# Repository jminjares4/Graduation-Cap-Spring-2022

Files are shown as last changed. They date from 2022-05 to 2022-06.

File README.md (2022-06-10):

# Graduation Cap Spring 2022 :zap:

## **Description**
This upcoming May, I will be graduating with my **Master of Science in Computer Engineering** from [The University of Texas at El Paso](https://www.utep.edu/engineering/ece/index.html)! Therefore, I decided to create a custom graduation cap to decorate as a true *engineer*. The graduation cap will utlize ARM Cortex M0 microcontroller with addtional sensors, LEDs, and NFC to store data.

## **Firmware**
- [x] Utlize open source Real-Time Operating System: [FreeRTOS]()
- [x] ARM Cortex M0+ micocontroller
- [x] Low power mode
- [x] custom drivers
## **Hardware**
- [x] Fixed USB data lines
  - [x] Update USB &pm; datalines with 90 ohms impedance
- [x] Open source development Electronic Design Automation (EDA): [KiCad]()
- [x] Two layer Printed Circuit Board (PCB)
- [x] Source Components
  - [x] LEDs
  - [x] ADLX335
  - [x] Lithium battery
  - [x] RP2040 custom board
- [x] Developed schematic
- [x] Developed printed circuit board
- [x] Board layout 4.74" * 4.74" with 45 degree rotation

## **Graduation Cap**
 

## **Development**
|**Software** | **Microcontroller** | **Hardware Design** |
| :---: | :---: | :---: |
| |  |  |

## **Author:**
* [**Jesus Minjares**](https://github.com/jminjares4)<br>
  * Master of Science in Computer Engineering<br>
 


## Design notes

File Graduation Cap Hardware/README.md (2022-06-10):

# Graduation Cap Spring 2022 :zap:
## **Description**

The graduation cap was developed KiCad.



## **Hardware**
- [x] Open source development Electronic Design Automation (EDA): [KiCad]()
- [x] Two layer Printed Circuit Board (PCB)
- [x] Source Components
  - [x] LEDs
  - [x] ADLX335
  - [x] Lithium battery
  - [x] RP2040 custom board
- [x] Developed schematic
- [x] Developed printed circuit board
- [x] Board layout 4.74" * 4.7" with 45 degree rotation

## **Graduation Schematic**
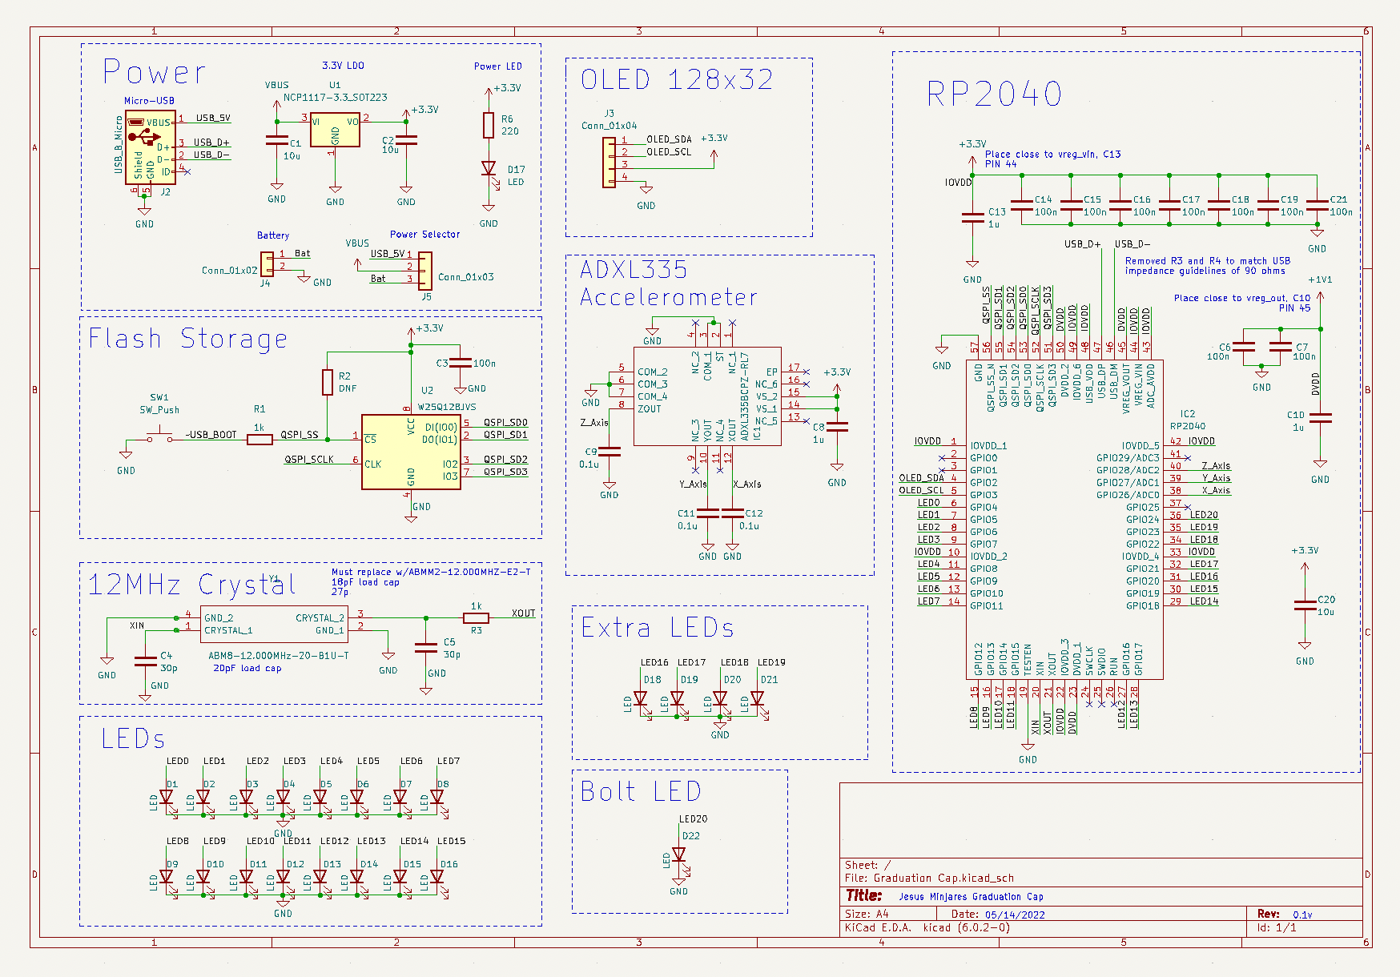
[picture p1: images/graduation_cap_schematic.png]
Schematic


## **Graduation Cap PCB**
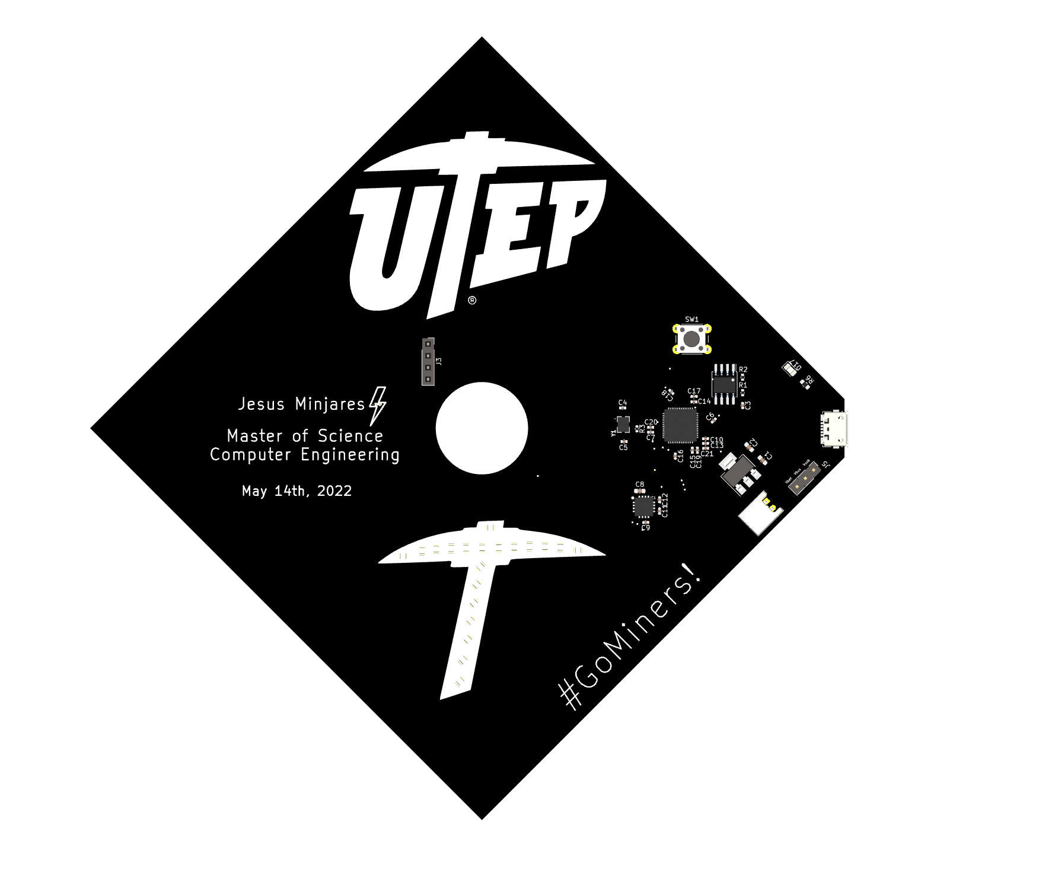
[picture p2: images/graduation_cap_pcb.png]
PCB

## **Author:**
* [**Jesus Minjares**](https://github.com/jminjares4)<br>
  * Master of Science in Computer Engineering<br>
 


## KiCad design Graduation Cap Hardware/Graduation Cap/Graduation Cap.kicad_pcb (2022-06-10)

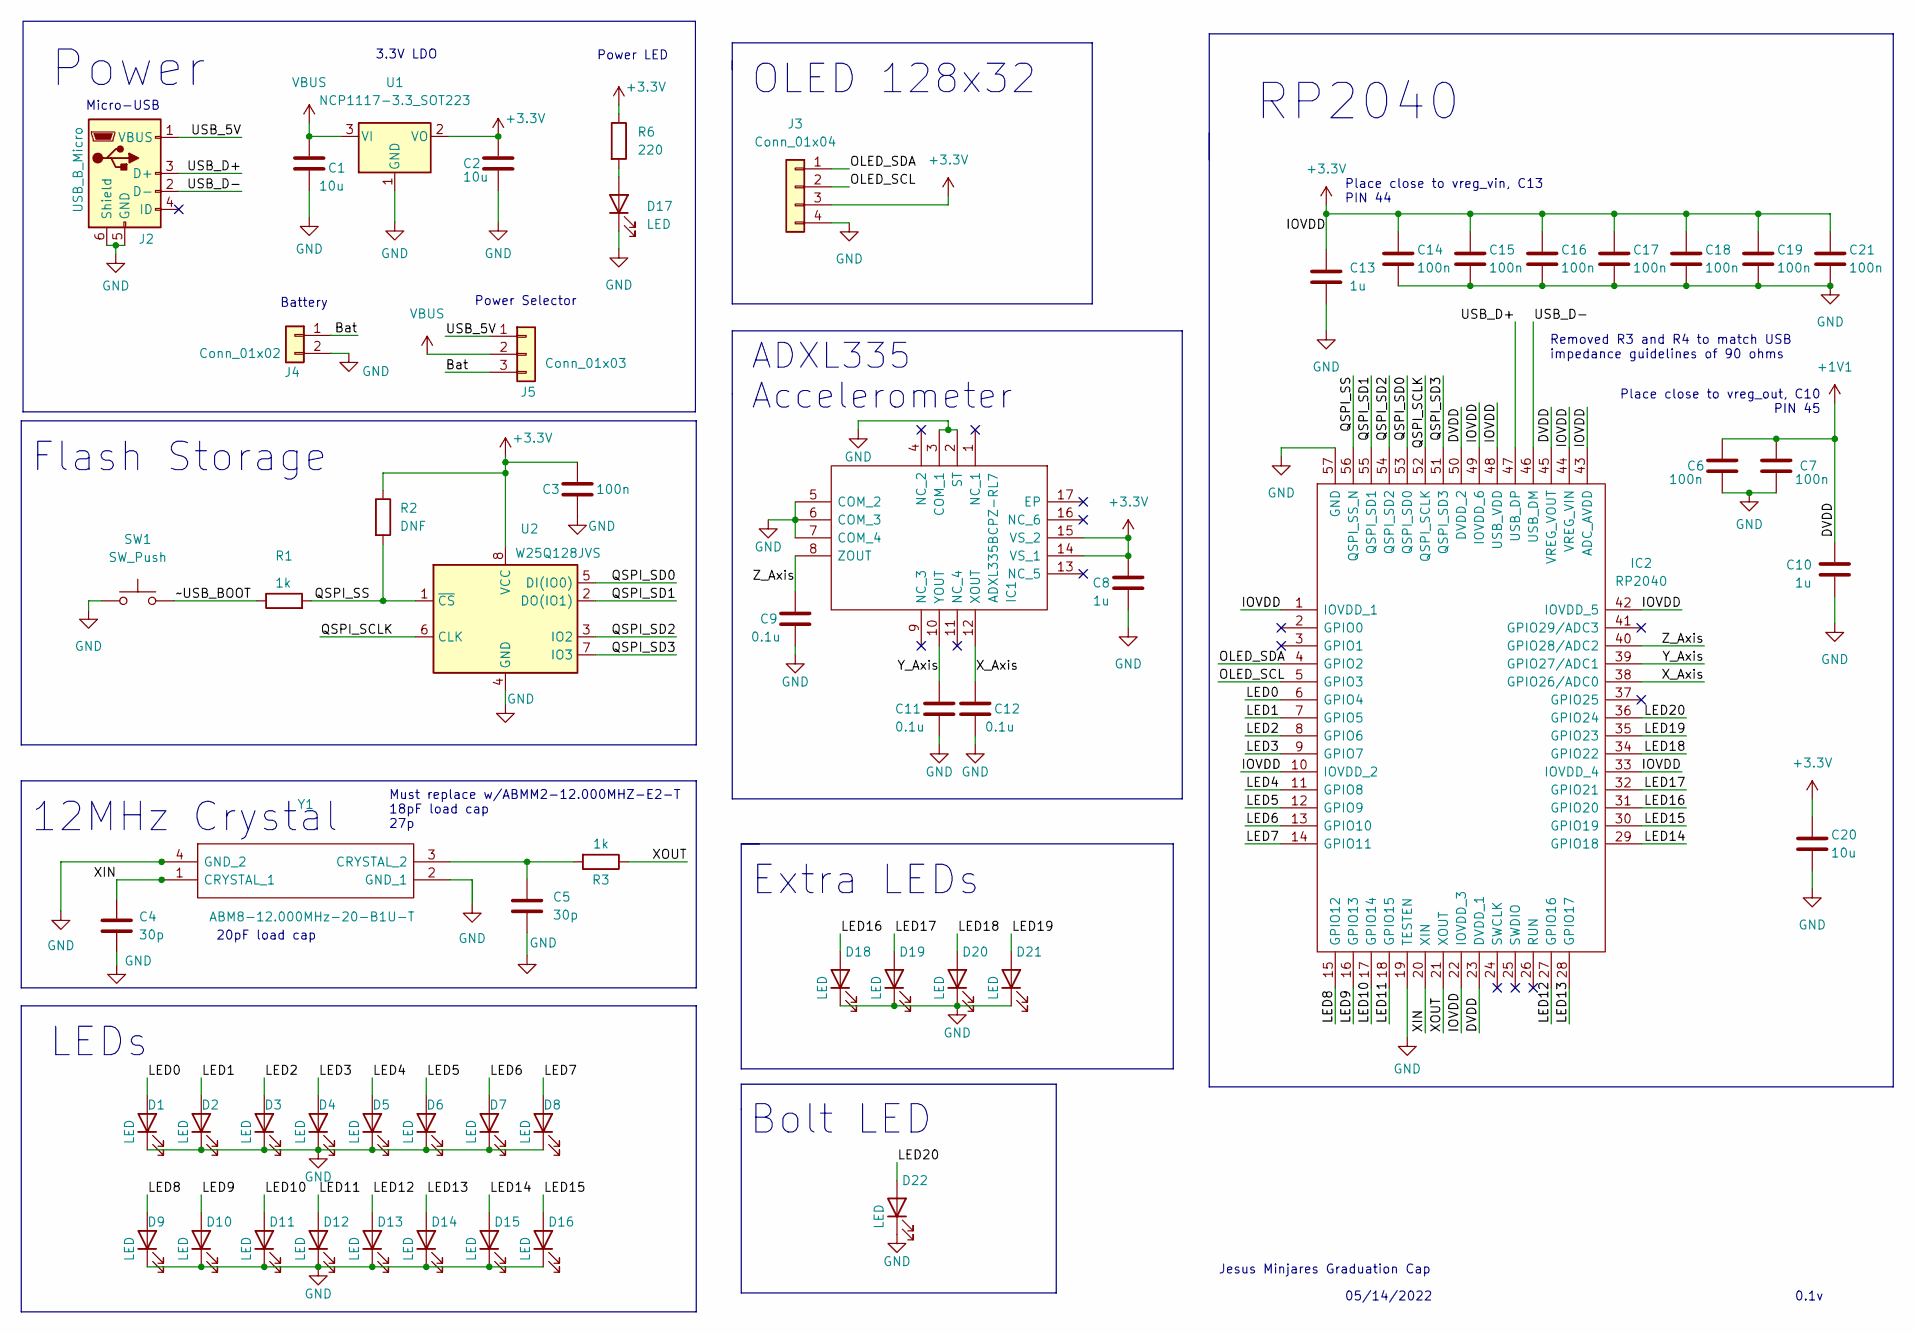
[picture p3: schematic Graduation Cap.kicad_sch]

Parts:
C1, C2: 10u; C_0603_1608Metric
C3, C6, C7, C14, C15, C16, C17, C18, C19, C21: 100n; C_0402_1005Metric
C4, C5: 30p; C_0402_1005Metric
C8: 1u; C_0603_1608Metric
C9, C11, C12: 0.1u; C_0402_1005Metric
C10, C13: 1u; C_0402_1005Metric
C20: 10u; C_0402_1005Metric
D1, D2, D3, D4, D5, D6, D7, D8, D9, D10, D11, D12, D13, D14, D15, D16, D17, D18, D19, D20, D21: LED; LED_0805_2012Metric
D22: LED; LED_0402_1005Metric
IC1: ADXL335BCPZ-RL7; QFN65P400X400X150-17N-D; Manufacturer_Part_Number ADXL335BCPZ-RL7; Mouser Part Number 584-ADXL335BCPZ-R7
IC2: RP2040; QFN40P700X700X90-57N-D; Manufacturer_Part_Number RP2040
J2: USB_B_Micro; USB_Micro-B_Molex_47346-0001
J3: Conn_01x04; PinSocket_1x04_P2.54mm_Vertical
J4: Conn_01x02; JST_PH_S2B-PH-K_1x02_P2.00mm_Horizontal
J5: Conn_01x03; PinHeader_1x03_P2.54mm_Vertical
R1, R3: 1k; R_0402_1005Metric
R2: DNF; R_0402_1005Metric
R6: 220; R_0603_1608Metric
SW1: SW_Push; SW_PUSH_6mm
U1: NCP1117-3.3_SOT223; SOT-223-3_TabPin2
U2: W25Q128JVS; SOIC-8_5.23x5.23mm_P1.27mm
Y1: ABM8-12.000MHz-20-B1U-T; ABM812000MHz20B1UT; Manufacturer_Part_Number ABM8-12.000MHz-20-B1U-T; Mouser Part Number 815-M812000MHZ20B1UT

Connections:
+1V1: C6.1, C7.1, C10.1, IC2.23 (DVDD_1), IC2.45 (VREG_VOUT), IC2.50 (DVDD_2)
+3V3: C2.1, C3.1, C8.2, C13.1, C14.1, C15.1, C16.1, C17.1, C18.1, C19.1, C20.1, C21.1, IC1.14 (VS_1), IC1.15 (VS_2), IC2.1 (IOVDD_1), IC2.10 (IOVDD_2), IC2.22 (IOVDD_3), IC2.33 (IOVDD_4), IC2.42 (IOVDD_5), IC2.43 (ADC_AVDD), IC2.44 (VREG_VIN), IC2.48 (USB_VDD), IC2.49 (IOVDD_6), J3.3, R2.1, R6.1, U1.2 (VO), U2.8 (VCC)
/Bat: J4.1, J5.3
/LED0: D1.2 (A), IC2.6 (GPIO4)
/LED1: D2.2 (A), IC2.7 (GPIO5)
/LED2: D3.2 (A), IC2.8 (GPIO6)
/LED3: D4.2 (A), IC2.9 (GPIO7)
/LED4: D5.2 (A), IC2.11 (GPIO8)
/LED5: D6.2 (A), IC2.12 (GPIO9)
/LED6: D7.2 (A), IC2.13 (GPIO10)
/LED7: D8.2 (A), IC2.14 (GPIO11)
/LED8: D9.2 (A), IC2.15 (GPIO12)
/LED9: D10.2 (A), IC2.16 (GPIO13)
/LED10: D11.2 (A), IC2.17 (GPIO14)
/LED11: D12.2 (A), IC2.18 (GPIO15)
/LED12: D13.2 (A), IC2.27 (GPIO16)
/LED13: D14.2 (A), IC2.28 (GPIO17)
/LED14: D15.2 (A), IC2.29 (GPIO18)
/LED15: D16.2 (A), IC2.30 (GPIO19)
/LED16: D18.2 (A), IC2.31 (GPIO20)
/LED17: D19.2 (A), IC2.32 (GPIO21)
/LED18: D20.2 (A), IC2.34 (GPIO22)
/LED19: D21.2 (A), IC2.35 (GPIO23)
/LED20: D22.2 (A), IC2.36 (GPIO24)
/OLED_SCL: IC2.5 (GPIO3), J3.2
/OLED_SDA: IC2.4 (GPIO2), J3.1
/QSPI_SCLK: IC2.52 (QSPI_SCLK), U2.6 (CLK)
/QSPI_SD0: IC2.53 (QSPI_SD0), U2.5 (DI(IO0))
/QSPI_SD1: IC2.55 (QSPI_SD1), U2.2 (DO(IO1))
/QSPI_SD2: IC2.54 (QSPI_SD2), U2.3 (IO2)
/QSPI_SD3: IC2.51 (QSPI_SD3), U2.7 (IO3)
/QSPI_SS: IC2.56 (QSPI_SS_N), R1.2, R2.2, U2.1 (~CS)
/USB_5V: J2.1 (VBUS), J5.1
/USB_D+: IC2.47 (USB_DP), J2.3 (D+)
/USB_D-: IC2.46 (USB_DM), J2.2 (D-)
/XIN: C4.1, IC2.20 (XIN), Y1.1 (CRYSTAL_1)
/XOUT: IC2.21 (XOUT), R3.1
/X_Axis: C12.2, IC1.12 (XOUT), IC2.38 (GPIO26/ADC0)
/Y_Axis: C11.1, IC1.10 (YOUT), IC2.39 (GPIO27/ADC1)
/Z_Axis: C9.1, IC1.8 (ZOUT), IC2.40 (GPIO28/ADC2)
/~USB_BOOT: R1.1, SW1.2
GND: C1.2, C2.2, C3.2, C4.2, C5.2, C6.2, C7.2, C8.1, C9.2, C10.2, C11.2, C12.1, C13.2, C14.2, C15.2, C16.2, C17.2, C18.2, C19.2, C20.2, C21.2, D1.1 (K), D2.1 (K), D3.1 (K), D4.1 (K), D5.1 (K), D6.1 (K), D7.1 (K), D8.1 (K), D9.1 (K), D10.1 (K), D11.1 (K), D12.1 (K), D13.1 (K), D14.1 (K), D15.1 (K), D16.1 (K), D17.1 (K), D18.1 (K), D19.1 (K), D20.1 (K), D21.1 (K), D22.1 (K), IC1.2 (ST), IC1.3 (COM_1), IC1.5 (COM_2), IC1.6 (COM_3), IC1.7 (COM_4), IC2.19 (TESTEN), IC2.57 (GND), J2.5 (GND), J2.6 (Shield), J3.4, J4.2, SW1.1, U1.1 (GND), U2.4 (GND), Y1.2 (GND_1), Y1.4 (GND_2)
unnamed: C5.1, R3.2, Y1.3 (CRYSTAL_2)
unnamed: D17.2 (A), R6.2
VBUS: C1.1, J5.2, U1.3 (VI)

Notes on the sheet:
Place close to vreg_vin, C13 PIN 44
Micro-USB
Power
05/14/2022
Must replace w/ABMM2-12.000MHZ-E2-T 18pF load cap 27p
Jesus Minjares Graduation Cap
RP2040
3.3V LDO
Power Selector
20pF load cap
ADXL335 Accelerometer
0.1v
OLED 128x32
Extra LEDs
Place close to vreg_out, C10 PIN 45
Removed R3 and R4 to match USB impedance guidelines of 90 ohms
Bolt LED
Flash Storage
LEDs
Battery
Power LED
12MHz Crystal

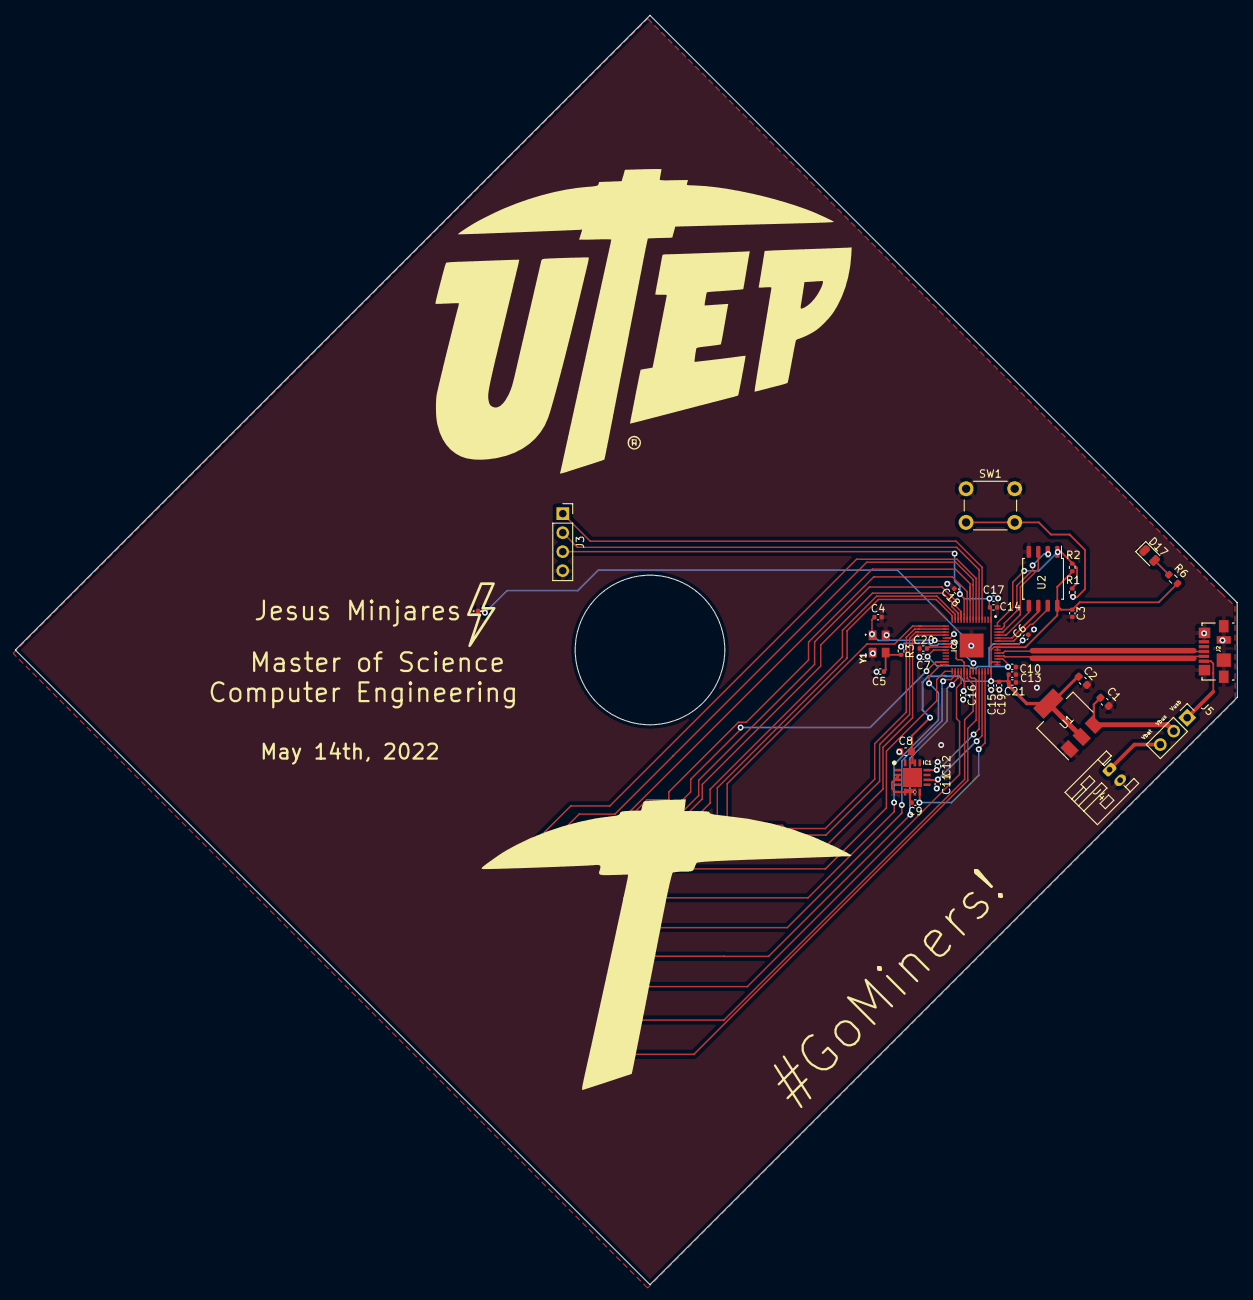
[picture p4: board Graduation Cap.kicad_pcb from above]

Board: 2 copper layers, 163.4 x 169.7 mm, 57 parts (0 on the bottom side), 45 nets.

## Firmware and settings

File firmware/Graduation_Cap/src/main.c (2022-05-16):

/**
 * @file main.c
 * @author Jesus Minjares (https://www.github.com/jminjares4)
 * @brief 
 * @version 0.1
 * @date 2022-03-16
 * 
 * @copyright Copyright (c) 2022
 * 
 */

#include <FreeRTOS.h>
#include <FreeRTOSConfig.h>
#include <task.h>
#include <stdio.h>
#include "pico/stdlib.h"

#define TOTAL_LEDS 20

/**
 * @brief Enumeration of the led current state
 * 
 */
typedef enum led_state_t{
    LOW,  /**< GPIO is 0  or logic low */
    HIGH, /**< GPIO is 1 or logic high */
}led_state_t;

/**
 * @brief Structure that will represent the pickaxe in the
 *        graduation cap
 * 
 */
typedef struct PickAxe{
    uint led[TOTAL_LEDS];           /**< LED array */
    led_state_t state[TOTAL_LEDS];  /**< State array */
}PickAxe;

/**
 * @brief Structure that will represent the ADXL335 sensor that will
 *        store the analog readings of all the axis.
 * 
 */
typedef struct Accelerometer{
    uint x_axis; /**< X axis */
    uint y_axis; /**< Y axis */
    uint z_axis; /**< Z axis */
}Accelerometer;

/**
 * @brief Structure that will represent the Bolt 
 *        placed in the gradauation cap
 * 
 */
typedef struct Bolt{
    uint led; /**< Bolt gpio */
    led_state_t state; /**< Bolt gpio state */
}Bolt;

/**
 * @brief Update LED state to HIGH or LOW: @see gpio_get(uint gpio)
 * 
 * @param gpio GPIO pin that will be read 
 * @return led_state_t 
 */
led_state_t updateState(uint gpio);

/**
 * @brief Toggle the Bolt gpio and update it state
 * 
 * @param bolt pass by reference bolt
 */
void bolt_toggle(Bolt *bolt);


/**
 * @brief Led task to verify FreeRTOS 
 * 
 * @param param generic void * to pass as arguement
 */
void led_task(void *param){   

    const uint led = *(uint *)(param); //deference void *
    //initialize GPIO
    gpio_init(led);
    gpio_set_dir(led, GPIO_OUT);
    //loop
    while (true) {
        gpio_put(led, 1); //turn on
        vTaskDelay(1000/portTICK_PERIOD_MS);
        gpio_put(led, 0); //turn off
        vTaskDelay(1000/portTICK_PERIOD_MS);
    }
}

/**
 * @brief Bolt task that will toggle every 500ms
 * 
 * @param param pass reference argument to the task
 */
void bolt_task(void *param){
    //initialize bolt to GPIO 20, and OFF
    Bolt bolt = {.led = 22, .state = LOW};
    // initialize GPIO
    gpio_init(bolt.led);
    // set the GPIO direction
    gpio_set_dir(bolt.led, GPIO_OUT);

    while(1){
        bolt_toggle(&bolt); //toggle the bolt LED
        vTaskDelay(500/portTICK_PERIOD_MS); // 1 sec delay
    }
}

int main()
{
    static const uint num = 25; //store in static memory
    stdio_init_all(); //initialize stdio for USB/UART
    TaskHandle_t ledTaskHandle = NULL;
    TaskHandle_t boltTaskHandle = NULL;

    xTaskCreate(led_task, "LED_Task", 1024,  (void * const)&num, 1, &ledTaskHandle);
    xTaskCreate(bolt_task, "Bolt Task", 1024, NULL, 2, &boltTaskHandle);
    //start scheduler
    vTaskStartScheduler();
    
    //should not reach this line
    while(1){};
}

led_state_t updateState(uint gpio){
    uint val = gpio_get(gpio);
    return val ? HIGH : LOW; 
}

void bolt_toggle(Bolt *bolt){
    if(bolt->state){
        gpio_put(bolt->led, 0); //turn off
    }else{
        gpio_put(bolt->led, 1); // turn on
    }
    //update state
    bolt->state = updateState(bolt->led);
    return;
}

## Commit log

2022-03-26 Added kicad rendering
2022-04-03 Added custom structures: bolt, accelerometer, and pickaxe
2022-05-16 Added hardware
    [Graduation Cap-CuBottom.gbr, Graduation Cap-CuTop.gbr, Graduation Cap-EdgeCuts.gbr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]
2022-05-16 Fix schematic
    [Graduation Cap.kicad_sch]
2022-06-10 Updated pcb
    [Graduation Cap-CuBottom.gbr, Graduation Cap-CuTop.gbr, Graduation Cap-EdgeCuts.gbr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]
2022-06-10 Updated readme with latest gif and schematic
2022-06-10 Updated images to the latest version of board
2022-06-10 Updated schematic and pcb layout
